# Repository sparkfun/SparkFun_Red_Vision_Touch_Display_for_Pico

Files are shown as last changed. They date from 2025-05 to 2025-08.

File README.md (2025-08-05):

SparkFun Red Vision Touch Display for Pico
=========================================

SparkFun Red Vision Touch Display for Pico (https://www.sparkfun.com/sparkfun-red-vision-touch-display-for-pico.html)

*[SparkFun Red Vision Touch Display for Pico](https://www.sparkfun.com/sparkfun-red-vision-touch-display-for-pico.html)*

The SparkFun Red Vision Touch Display for Pico features a 2.0", 320x240px capacative touch LCD mounted on a breakout board designed to plug directly into the Control Board on the [Experiential Robotics Platform (XRP) Kit](https://www.sparkfun.com/experiential-robotics-platform-xrp-kit.html) as well as Raspberry Pi Picos. This display board includes a connector specifically designed to allow you to plug the [SparkFun Red Vision Camera Board - HM01B0 (Color)](https://www.sparkfun.com/sparkfun-red-vision-camera-board-hm01b0-color.html) or other 2x9 connection type camera boards into the display board. Both of these boards work with the SparkFun MicroPython OpenCV port so you can add image processing, object detection, contour detection and other advanced machine vision and display features to your XRP robot. The [SparkFun Red Vision Kit for XRP](https://www.sparkfun.com/sparkfun-pico-vision-kit-for-xrp.html) contains both the display board as well as a camera board with headers for users who want to use both boards on their XRP robot with no soldering required. 

Repository Contents
-------------------

* **/Hardware** - Eagle design files (.brd, .sch)

Documentation
--------------
* **[SparkFun Red Vision MicroPython Package](https://github.com/sparkfun/red_vision/tree/main)** - MicroPython package for the SparkFun Red Vision Camera Board - HM01B0 (Color).
* **[SparkFun MicroPython OpenCV](https://github.com/sparkfun/micropython-opencv)** - MicroPython port of OpenCV code library.
* **[SparkFun MicroPython Firmware Releases](https://github.com/sparkfun/micropython/releases)** - SparkFun MicroPython firmware releases.
* **[SparkFun Red Vision Kit for XRP Hookup Guide](https://docs.sparkfun.com/SparkFun_Red_Vision_Kit_for_XRP/introduction)** - Basic hookup guide for the SparkFun Red Vision Kit for XRP (includes the Red Vision Camera Board - HM01B0).

Product Versions
----------------
* [LCD-29467](https://www.sparkfun.com/sparkfun-red-vision-touch-display-for-pico.html) - Initial release of the SparkFun Red Vision Touch Display for Pico

License Information
-------------------

This product is _**open source**_! 

Please review the LICENSE.md file for license information. 

If you have any questions or concerns on licensing, please contact technical support on our [SparkFun forums](https://forum.sparkfun.com/viewforum.php?f=152).

Distributed as-is; no warranty is given.

- Your friends at SparkFun.

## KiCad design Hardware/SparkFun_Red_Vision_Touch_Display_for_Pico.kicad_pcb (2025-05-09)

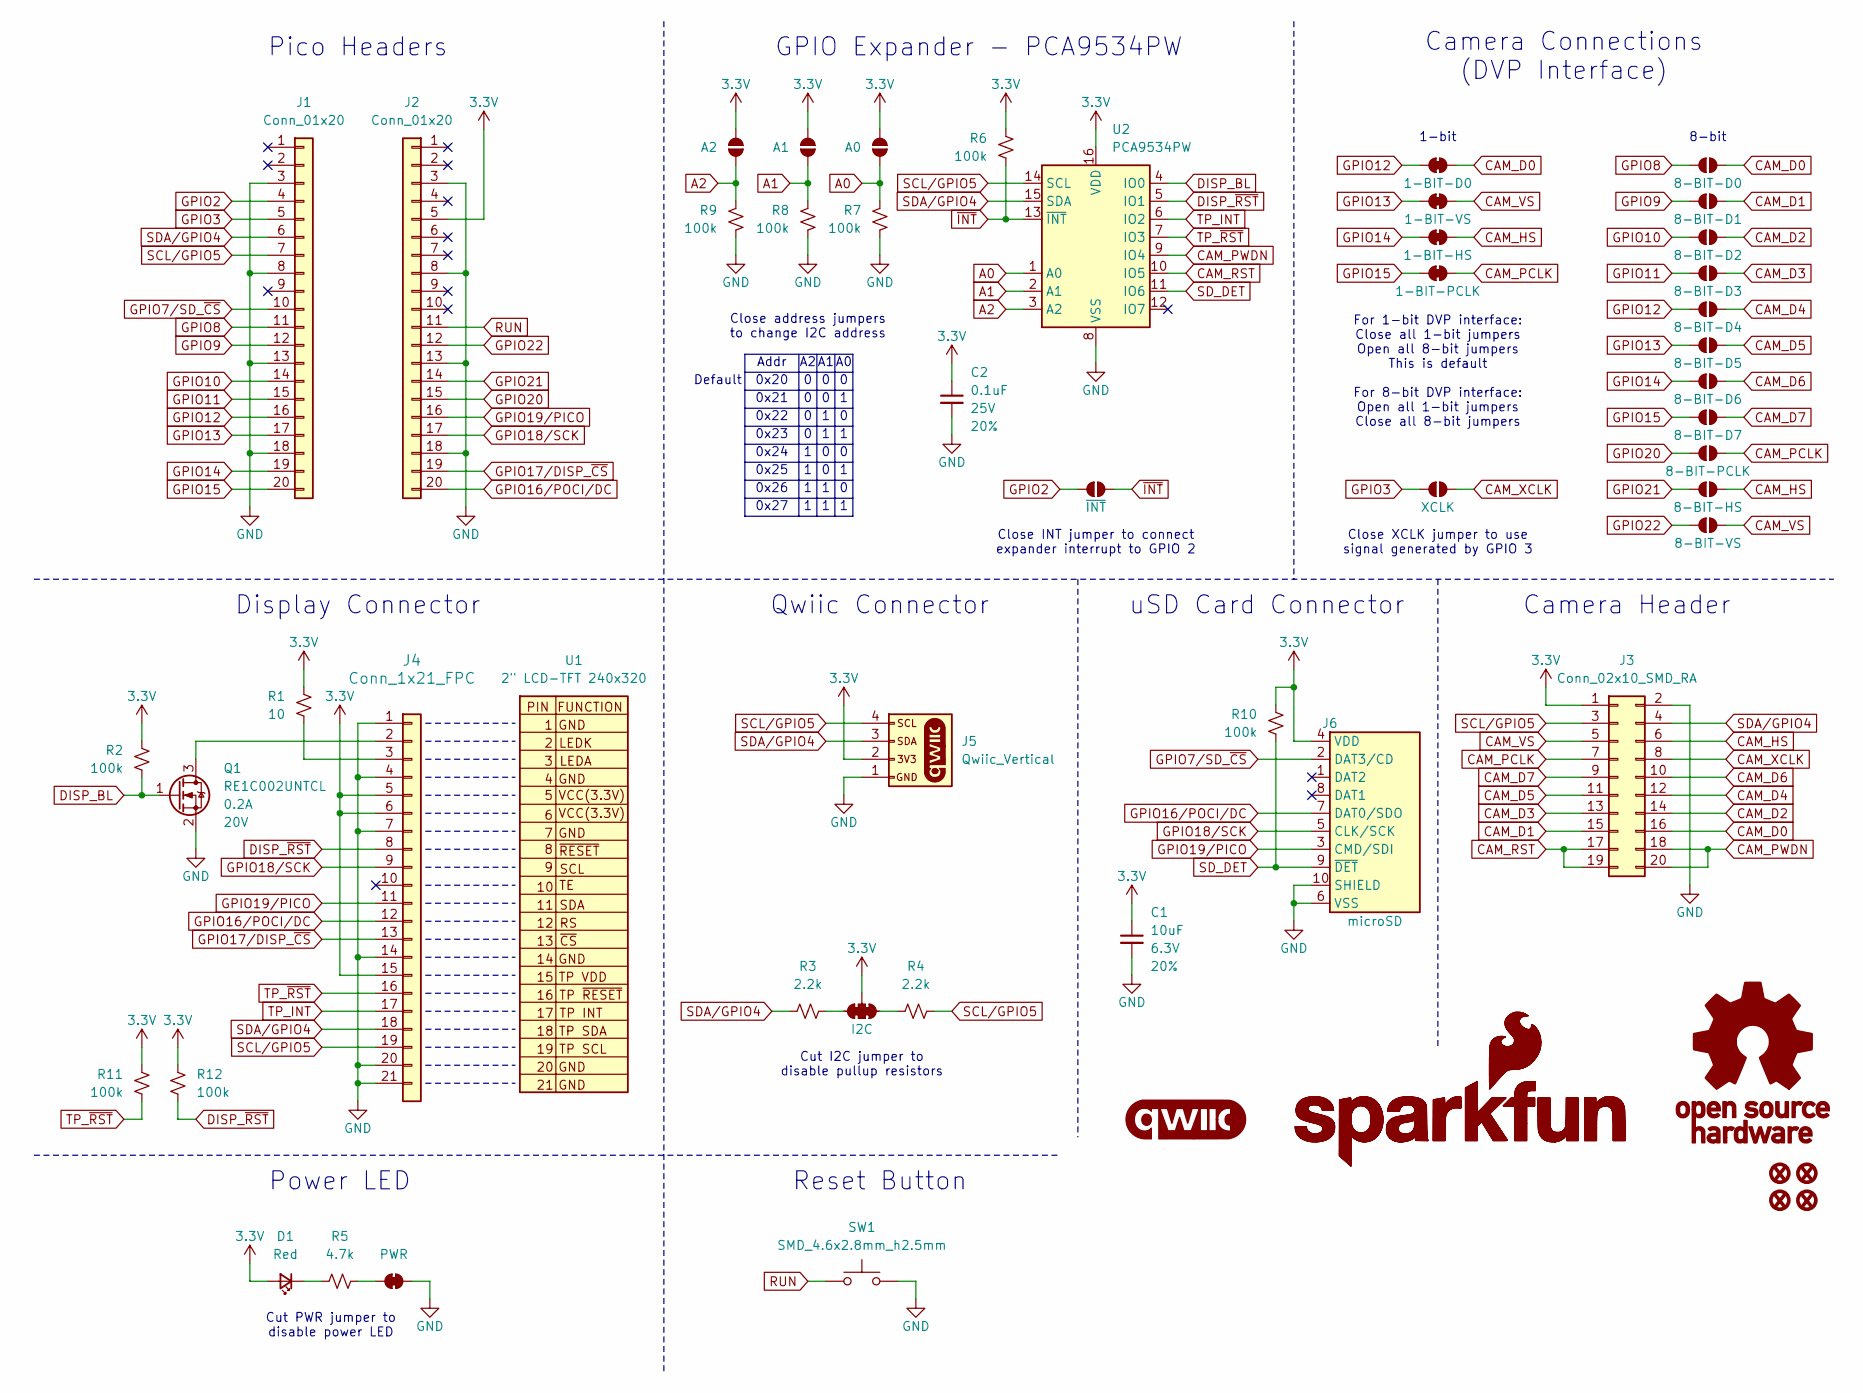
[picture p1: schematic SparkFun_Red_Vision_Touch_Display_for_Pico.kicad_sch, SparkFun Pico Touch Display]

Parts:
C1: 10uF; C_0603_1608Metric; Voltage 6.3V; Tolerance 20%
C2: 0.1uF; C_0603_1608Metric; Voltage 25V; Tolerance 20%
D1: Red; LED_0603_1608Metric_Red
FID1, FID2, FID3, FID4: Fiducial_0.5mm; Fiducial_0.5mm_Mask1mm
G1: SparkFun_Logo; SparkFun_Logo_8mm
G2: SparkFun_Logo
G3: OSHW_Logo; Creative_Commons_License
G4: qwiic_Logo
J1, J2: Conn_01x20; 1x20_SMD_Pin1RightUp
J3: Conn_02x10_SMD_RA; 2x10_SMD_RA
J4: Conn_1x21_FPC; CONN21_FH35C-21S_HIR
J5: Qwiic_Vertical; JST_SMD_1.0mm-4_Vertical_Black
J6: microSD; microSD_External_Pin
JP1: I2C; Jumper_3_NC-2_Trace
JP2: 8-BIT-D0; Jumper_2_NO
JP3: 8-BIT-VS; Jumper_2_NO
JP4: 8-BIT-HS; Jumper_2_NO
JP5: 8-BIT-PCLK; Jumper_2_NO
JP6: 8-BIT-D3; Jumper_2_NO
JP7: 8-BIT-D2; Jumper_2_NO
JP8: 8-BIT-D1; Jumper_2_NO
JP9: 8-BIT-D4; Jumper_2_NO
JP10: 8-BIT-D5; Jumper_2_NO
JP11: 8-BIT-D6; Jumper_2_NO
JP12: 8-BIT-D7; Jumper_2_NO
JP13: XCLK; Jumper_2_NO
JP14: A0; Jumper_2_NO
JP15: A1; Jumper_2_NO
JP16: A2; Jumper_2_NO
JP17: 1-BIT-PCLK; Jumper_2_NC_Trace
JP18: 1-BIT-HS; Jumper_2_NC_Trace
JP19: 1-BIT-VS; Jumper_2_NC_Trace
JP20: 1-BIT-D0; Jumper_2_NC_Trace
JP21: PWR; Jumper_2_NC_Trace
JP22: ~{INT}; Jumper_2_NO
Q1: RE1C002UNTCL; SC-89 SOT-490
R1: 10; R_0603_1608Metric
R2, R6, R7, R8, R9, R10, R11, R12: 100k; R_0603_1608Metric
R3, R4: 2.2k; R_0603_1608Metric
R5: 4.7k; R_0603_1608Metric
SW1: SMD_4.6x2.8mm_h2.5mm; Push_SMD_4.6x2.8mm_h2.5mm
U1: 2" LCD-TFT 240x320; Waveshare_2_Inch_Outline
U2: PCA9534PW; TSSOP-16_4.4x5mm_P0.65mm

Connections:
3.3V: C1.1, C2.1, D1.2 (A), J2.5, J3.1, J4.5, J4.6, J4.15, J5.2, J6.4 (VDD), JP1.2 (B), JP14.2 (B), JP15.2 (B), JP16.2 (B), R1.2, R2.2, R6.2, R10.2, R11.2, R12.2, U2.16 (VDD)
A0: JP14.1 (A), R7.2, U2.1 (A0)
A1: JP15.1 (A), R8.2, U2.2 (A1)
A2: JP16.1 (A), R9.2, U2.3 (A2)
CAM_D0: J3.16, JP2.2 (B), JP20.1 (A)
CAM_D1: J3.15, JP8.1 (A)
CAM_D2: J3.14, JP7.1 (A)
CAM_D3: J3.13, JP6.1 (A)
CAM_D4: J3.12, JP9.1 (A)
CAM_D5: J3.11, JP10.1 (A)
CAM_D6: J3.10, JP11.1 (A)
CAM_D7: J3.9, JP12.1 (A)
CAM_HS: J3.6, JP4.2 (B), JP18.1 (A)
CAM_PCLK: J3.7, JP5.2 (B), JP17.1 (A)
CAM_PWDN: J3.18, J3.20, U2.9 (IO4)
CAM_RST: J3.17, J3.19, U2.10 (IO5)
CAM_VS: J3.5, JP3.2 (B), JP19.1 (A)
CAM_XCLK: J3.8, JP13.1 (A)
DISP_BL: Q1.1 (G), R2.1, U2.4 (IO0)
DISP_~RST: J4.8, R12.1, U2.5 (IO1)
GND: C1.2, C2.2, J1.3, J1.8, J1.13, J1.18, J2.3, J2.8, J2.13, J2.18, J3.2, J4.1, J4.4, J4.7, J4.14, J4.20, J4.21, J5.1, J6.6 (VSS), J6.10 (SHIELD), JP21.2 (B), Q1.2 (S), R7.1, R8.1, R9.1, SW1.2, U2.8 (VSS)
GPIO2: J1.4, JP22.2 (B)
GPIO3: J1.5, JP13.2 (B)
GPIO7/SD_~CS: J1.10, J6.2 (DAT3/CD)
GPIO8: J1.11, JP2.1 (A)
GPIO9: J1.12, JP8.2 (B)
GPIO10: J1.14, JP7.2 (B)
GPIO11: J1.15, JP6.2 (B)
GPIO12: J1.16, JP9.2 (B), JP20.2 (B)
GPIO13: J1.17, JP10.2 (B), JP19.2 (B)
GPIO14: J1.19, JP11.2 (B), JP18.2 (B)
GPIO15: J1.20, JP12.2 (B), JP17.2 (B)
GPIO16/POCI/DC: J2.20, J4.12, J6.7 (DAT0/SDO)
GPIO17/DISP_~CS: J2.19, J4.13
GPIO18/SCK: J2.17, J4.9, J6.5 (CLK/SCK)
GPIO19/PICO: J2.16, J4.11, J6.3 (CMD/SDI)
GPIO20: J2.15, JP5.1 (A)
GPIO21: J2.14, JP4.1 (A)
GPIO22: J2.12, JP3.1 (A)
unnamed: D1.1 (K), R5.2
unnamed: J4.2, Q1.3 (D)
unnamed: J4.3, R1.1
unnamed: JP1.1 (A), R4.1
unnamed: JP1.3 (C), R3.2
unnamed: JP21.1 (A), R5.1
RUN: J2.11, SW1.1
SCL/GPIO5: J1.7, J3.3, J4.19, J5.4, R4.2, U2.14 (SCL)
SDA/GPIO4: J1.6, J3.4, J4.18, J5.3, R3.1, U2.15 (SDA)
SD_DET: J6.9 (~DET), R10.1, U2.11 (IO6)
TP_INT: J4.17, U2.6 (IO2)
TP_~RST: J4.16, R11.1, U2.7 (IO3)
~INT: JP22.1 (A), R6.1, U2.13 (~INT)

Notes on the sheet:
1-bit
0x20
8-bit
Cut PWR jumper to disable power LED
0x22
0x27
0x24
GPIO Expander - PCA9534PW
Camera Connections (DVP Interface)
Close address jumpers to change I2C address
Default
Addr
Qwiic Connector
Cut I2C jumper to disable pullup resistors
Pico Headers
Camera Header
0x26
For 1-bit DVP interface: Close all 1-bit jumpers Open all 8-bit jumpers This is default For 8-bit DVP interface: Open all 1-bit jumpers Close all 8-bit jumpers
0x23
Display Connector
Close XCLK jumper to use signal generated by GPIO 3
0x21
uSD Card Connector
0x25
Power LED
Reset Button
Close INT jumper to connect expander interrupt to GPIO 2

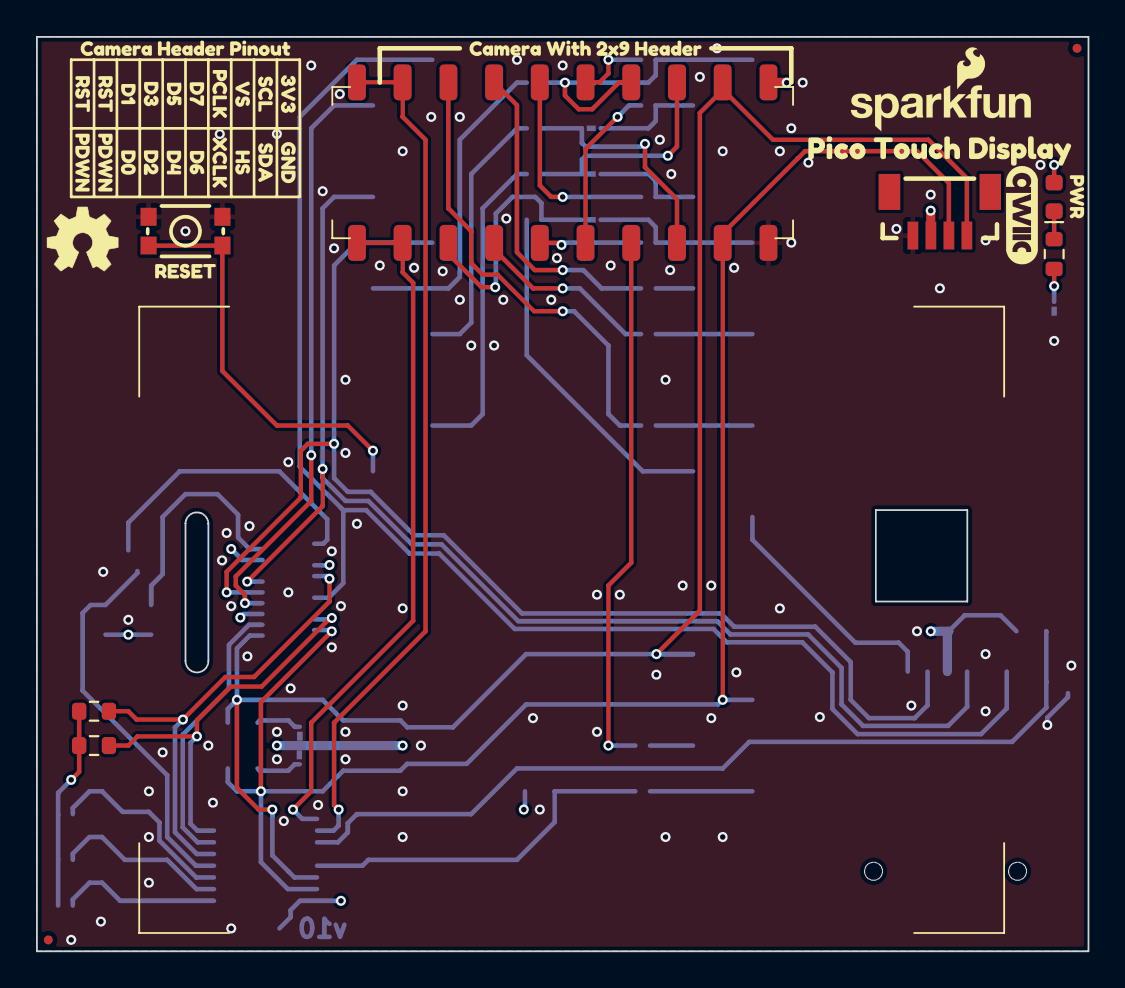
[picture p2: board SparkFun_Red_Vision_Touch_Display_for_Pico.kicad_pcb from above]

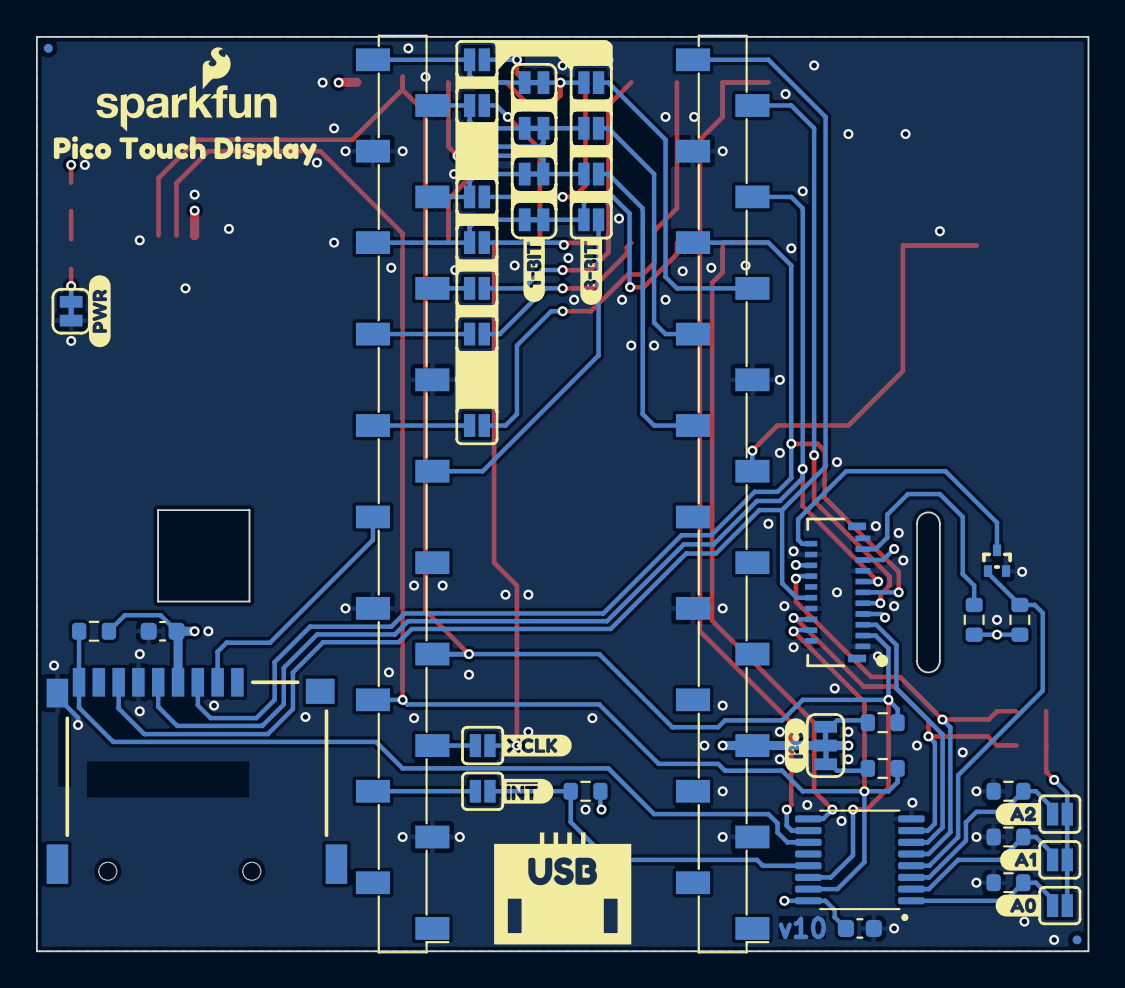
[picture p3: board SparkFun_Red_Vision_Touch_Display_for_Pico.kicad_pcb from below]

Board: 4 copper layers, 58.4 x 50.8 mm, 89 parts (52 on the bottom side), 52 nets.

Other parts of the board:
Ref**: Val**; OSHW_Logo_4mm
kibuzzard-67A69C5F, kibuzzard-67A69C5F#2: G***; kibuzzard-67A69C5F
kibuzzard-67A69CD2, kibuzzard-67A69CD2#2: G***; kibuzzard-67A69CD2
kibuzzard-67A69CDC: G***; kibuzzard-67A69CDC
kibuzzard-67A69CE2: G***; kibuzzard-67A69CE2
kibuzzard-67A69CE6: G***; kibuzzard-67A69CE6
kibuzzard-67A69CEA: G***; kibuzzard-67A69CEA
kibuzzard-67A69CFF: G***; kibuzzard-67A69CFF
kibuzzard-67A69D0C: G***; kibuzzard-67A69D0C
kibuzzard-67A69D0F: G***; kibuzzard-67A69D0F
kibuzzard-67A69D1B: G***; kibuzzard-67A69D1B
kibuzzard-67A69D2C: G***; kibuzzard-67A69D2C
kibuzzard-67A69D2F: G***; kibuzzard-67A69D2F
kibuzzard-67A69D05: G***; kibuzzard-67A69D05
kibuzzard-67A69D16: G***; kibuzzard-67A69D16
kibuzzard-67A69D28: G***; kibuzzard-67A69D28
kibuzzard-67A69D32: G***; kibuzzard-67A69D32
kibuzzard-67A69E51: G***; kibuzzard-67A69E51
kibuzzard-67A69E55: G***; kibuzzard-67A69E55
kibuzzard-67ABB7DF: G***; kibuzzard-67ABB7DF
kibuzzard-67B3EC79, kibuzzard-67B3EC79#2: G***; kibuzzard-67B3EC79
kibuzzard-67B3EC92: G***; kibuzzard-67B3EC92
kibuzzard-67B3F617: G***; kibuzzard-67B3F617
kibuzzard-67B3FF40: G***; kibuzzard-67B3FF40
kibuzzard-67B3FF54: G***; kibuzzard-67B3FF54
kibuzzard-67B3FFE0: G***; kibuzzard-67B3FFE0
kibuzzard-67C124A5: G***; kibuzzard-67C124A5
kibuzzard-67C651AF: G***; kibuzzard-67C651AF
kibuzzard-67C1248C: G***; kibuzzard-67C1248C
kibuzzard-67C6452E: G***; kibuzzard-67C6452E
kibuzzard-67C64429: G***; kibuzzard-67C64429
kibuzzard-67C64532: G***; kibuzzard-67C64532
kibuzzard-681E5A39: G***; kibuzzard-681E5A39
kibuzzard-681E525B: G***; kibuzzard-681E525B

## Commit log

2025-02-27 Add initial design
    [SparkFun_Pico_Touch_Display.kicad_pcb, SparkFun_Pico_Touch_Display.kicad_sch]
2025-02-28 Clean up design
    Finish routing
    Add power LED
    Move all schematic elements inside frame
    Update display 3D model
    Stitch together GND pours
    Add measures
    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
    [SparkFun_Pico_Touch_Display.kicad_pcb, SparkFun_Pico_Touch_Display.kicad_sch]
2025-02-28 Design review updates
    Rename jumpers to match silk
    Nudge traces to provide more isolation of I2C traces
    Add 10uF capacitor for uSD card
    Fix acid trap
    Rename MISO/MOSI to POCI/PICO
    Increase 3.3V trace width
    Change to 2 layer
    Update ordering notes
    [SparkFun_Pico_Touch_Display.kicad_pcb, SparkFun_Pico_Touch_Display.kicad_sch]
2025-03-04 Design review updates
    Change to 4 layer
    Add GPIO expander for control signals
    Connect uSD detection pin
    Fix typo in company name on schematic
    Update datahseet link for 21-pin FPC connector
    Update KiCad libraries
    [SparkFun_Pico_Touch_Display.kicad_pcb, SparkFun_Pico_Touch_Display.kicad_sch]
2025-03-17 Design review updates
    Fix NC flags on headers and GPIO expander
    Change In2.Cu to 3.3V instead of GND
    Fix MOSFET datasheet link
    Move Qwiic silk
    [SparkFun_Pico_Touch_Display.kicad_pcb, SparkFun_Pico_Touch_Display.kicad_sch]
2025-03-17 Actually save board file
    [SparkFun_Pico_Touch_Display.kicad_pcb]
2025-03-17 Review updates
    Add 2x20 connector PROD_ID
    Move R6
    Swap In1.Cu and In2.Cu
    [SparkFun_Pico_Touch_Display.kicad_pcb, SparkFun_Pico_Touch_Display.kicad_sch]
2025-03-17 Add missing PROD_ID values
    [SparkFun_Pico_Touch_Display.kicad_pcb, SparkFun_Pico_Touch_Display.kicad_sch]
2025-05-07 Move display connector to bottom
    Previous location was too easy to accidentally unlatch
    [SparkFun_Pico_Touch_Display.kicad_pcb]
2025-05-07 Change GPIO expander to PCA9534
    PCA9554 has internal pull-up resistors on IO pins, whereas PCA9534 does not. The pull-up resistors were causing problems with the camera not being enabled by default, so this will ensure the camera's pull-up/down resistors take priority.
    [SparkFun_Pico_Touch_Display.kicad_pcb, SparkFun_Pico_Touch_Display.kicad_sch]
2025-05-07 Bump version number to v10
    [SparkFun_Pico_Touch_Display.kicad_pcb, SparkFun_Pico_Touch_Display.kicad_sch]
2025-05-09 Fix acid trap on PWDN pad
    [SparkFun_Pico_Touch_Display.kicad_pcb]
2025-05-09 Add silk about 2x9 camera header position
    Also nudge header down to accommodate
    [SparkFun_Pico_Touch_Display.kicad_pcb]
2025-05-09 Add pullup resistors to TP and DISP RST nets
    [SparkFun_Pico_Touch_Display.kicad_pcb, SparkFun_Pico_Touch_Display.kicad_sch]
2025-08-05 Updating hardware filenames
    Updating hardware filenames to match product name.
    [SparkFun_Red_Vision_Touch_Display_for_Pico.kicad_pcb, SparkFun_Red_Vision_Touch_Display_for_Pico.kicad_sch]

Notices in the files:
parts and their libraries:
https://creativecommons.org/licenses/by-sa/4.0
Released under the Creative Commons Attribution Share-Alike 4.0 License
